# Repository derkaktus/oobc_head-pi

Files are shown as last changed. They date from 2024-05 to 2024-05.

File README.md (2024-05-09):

# OutofBand Console Server Head for Raspberry Pi

Upgrade your Raspberry Pi to an eight port serial console server for OoB management.

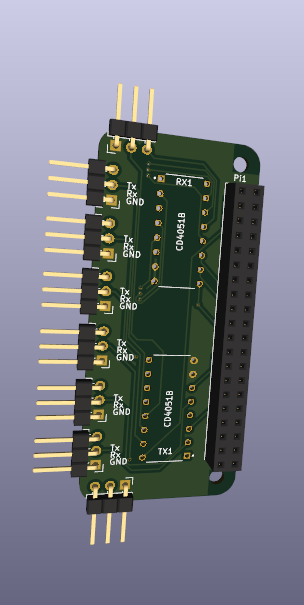
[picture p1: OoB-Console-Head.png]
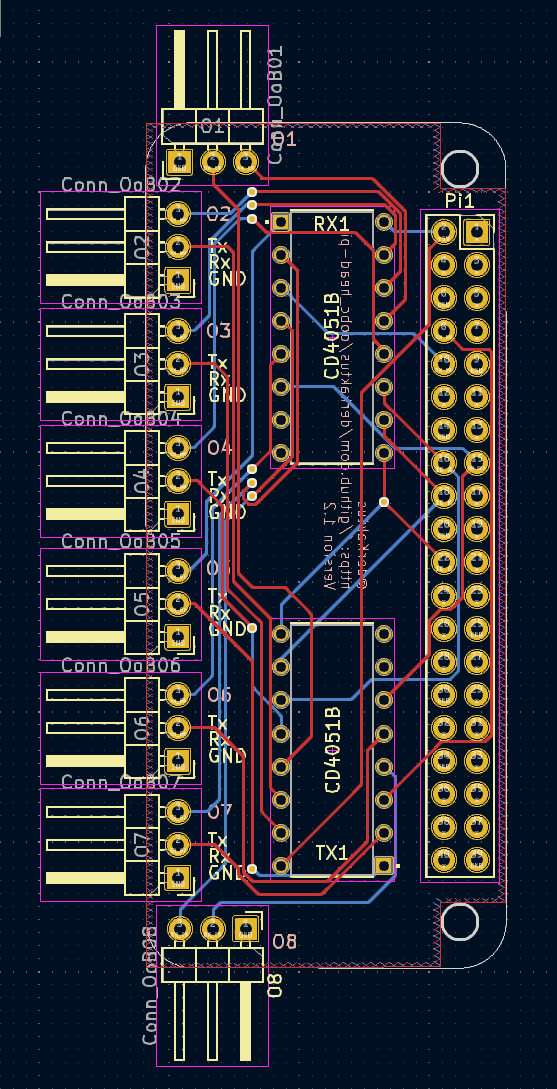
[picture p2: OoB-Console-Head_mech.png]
  
<br clear="left"/>
<br clear="right"/>

## Function
The head utilizes the build in UART capability of the raspberry pi (only UART0) and adds the 8 port switching capability. 
The port can be selected via pin 16, 18 and 22 a.k.a. **GPIO 22, 23** and **25** by adjusting their HIGH LOW state.

| PORT |GPIO>  | 22 | 23 | 25 |
|--|--| -- | -- | -- |
| 1 |  | 0 | 0 | 0 |
| 2 |  | 1 | 0 | 0 |
| 3 |  | 0 | 1 | 0 |
| 4 |  | 1 | 1 | 0 |
| 5 |  | 0 | 0 | 1 |
| 6 |  | 1 | 0 | 1 |
| 7 |  | 0 | 1 | 1 |
| 8 |  | 1 | 1 | 1 |

## Component
- 1x Pin Header 2x20 for Raspberry Pi
- 2x CD4051BE IC (Analog Multiplexer Single 8)

Optional: 
- 2x IC Socket 16 / 2x8 pin

Watch for the 2.54 mm pitch versions !!

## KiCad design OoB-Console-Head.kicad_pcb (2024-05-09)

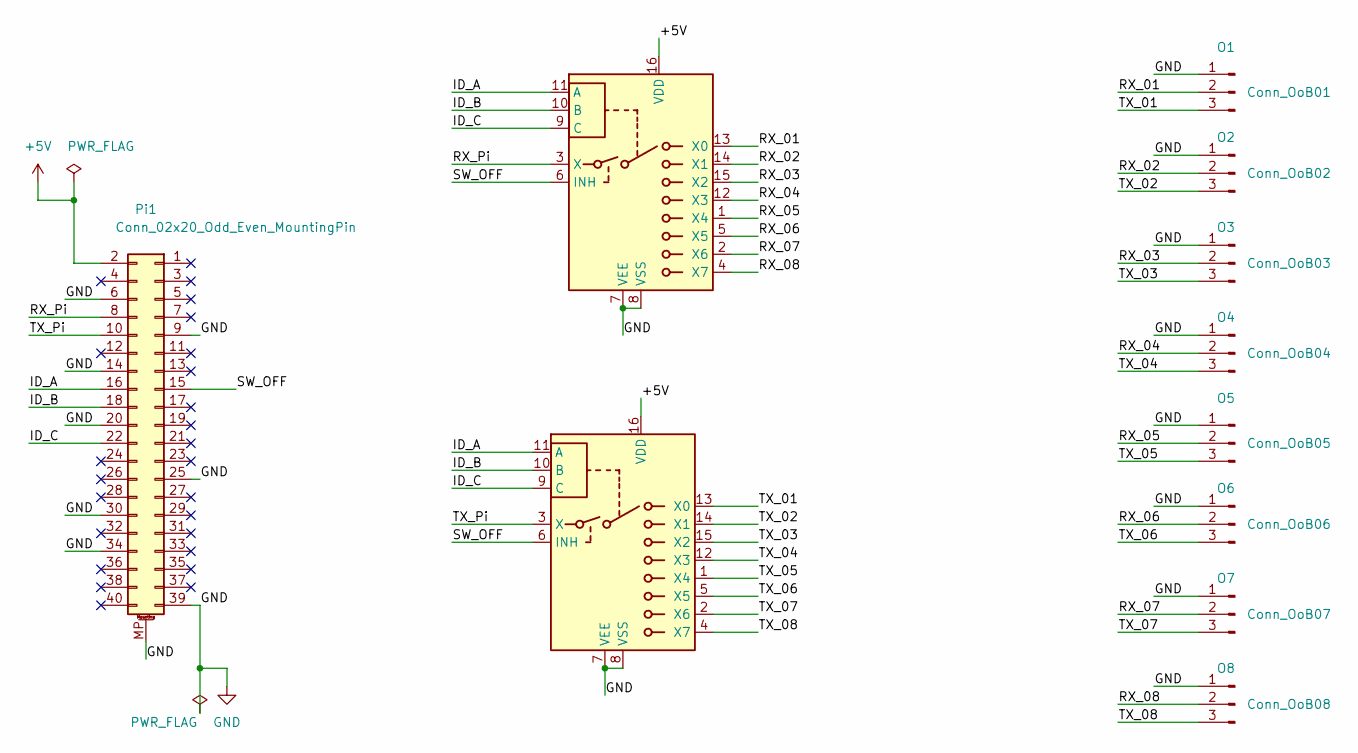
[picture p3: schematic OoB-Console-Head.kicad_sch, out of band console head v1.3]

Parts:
O1: Conn_OoB01; PinHeader_1x03_P2.54mm_Horizontal
O2: Conn_OoB02; PinHeader_1x03_P2.54mm_Horizontal
O3: Conn_OoB03; PinHeader_1x03_P2.54mm_Horizontal
O4: Conn_OoB04; PinHeader_1x03_P2.54mm_Horizontal
O5: Conn_OoB05; PinHeader_1x03_P2.54mm_Horizontal
O6: Conn_OoB06; PinHeader_1x03_P2.54mm_Horizontal
O7: Conn_OoB07; PinHeader_1x03_P2.54mm_Horizontal
O8: Conn_OoB08; PinHeader_1x03_P2.54mm_Horizontal
Pi1: Conn_02x20_Odd_Even_MountingPin; PinSocket_2x20_P2.54mm_Vertical
RX1: CD4051B; CD4051
TX1: CD4051B; CD4051

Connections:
+5V: Pi1.2, RX1.16 (VDD), TX1.16 (VDD)
/ID_A: Pi1.16, RX1.11 (A), TX1.11 (A)
/ID_B: Pi1.18, RX1.10 (B), TX1.10 (B)
/ID_C: Pi1.22, RX1.9 (C), TX1.9 (C)
/RX_01: O1.2, TX1.13 (X0)
/RX_02: O2.2, TX1.14 (X1)
/RX_03: O3.2, TX1.15 (X2)
/RX_04: O4.2, TX1.12 (X3)
/RX_05: O5.2, TX1.1 (X4)
/RX_06: O6.2, TX1.5 (X5)
/RX_07: O7.2, TX1.2 (X6)
/RX_08: O8.2, TX1.4 (X7)
/RX_Pi: Pi1.8, TX1.3 (X)
/SW_OFF: Pi1.15, RX1.6 (INH), TX1.6 (INH)
/TX_01: O1.3, RX1.13 (X0)
/TX_02: O2.3, RX1.14 (X1)
/TX_03: O3.3, RX1.15 (X2)
/TX_04: O4.3, RX1.12 (X3)
/TX_05: O5.3, RX1.1 (X4)
/TX_06: O6.3, RX1.5 (X5)
/TX_07: O7.3, RX1.2 (X6)
/TX_08: O8.3, RX1.4 (X7)
/TX_Pi: Pi1.10, RX1.3 (X)
GND: O1.1, O2.1, O3.1, O4.1, O5.1, O6.1, O7.1, O8.1, Pi1.6, Pi1.9, Pi1.14, Pi1.20, Pi1.25, Pi1.30, Pi1.34, Pi1.39, Pi1.MP (MountPin), RX1.7 (VEE), RX1.8 (VSS), TX1.7 (VEE), TX1.8 (VSS)

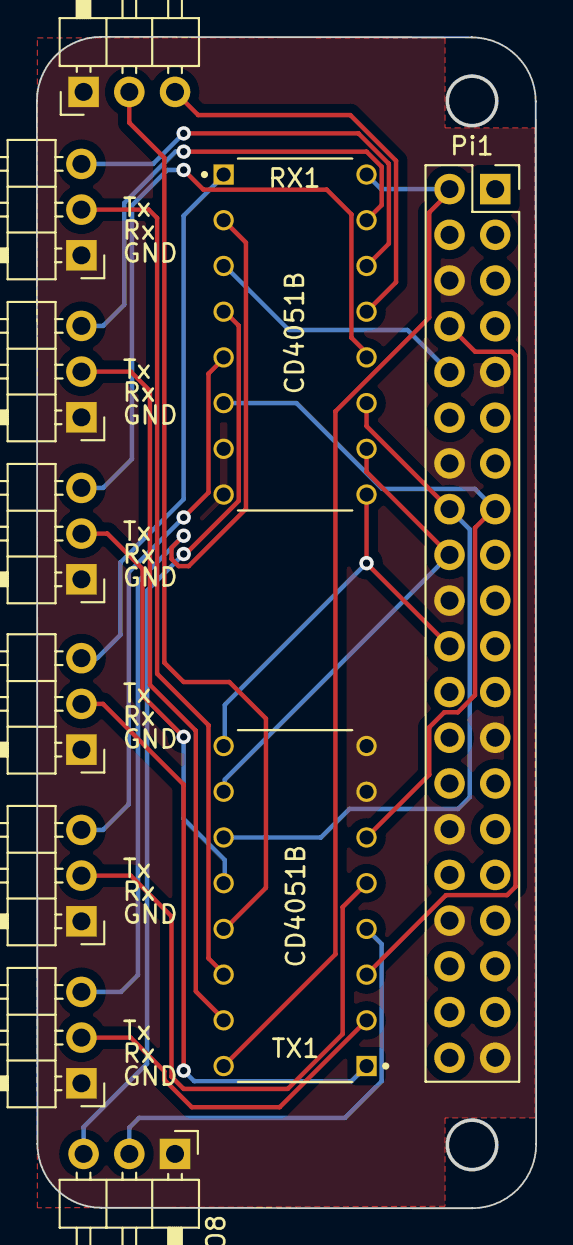
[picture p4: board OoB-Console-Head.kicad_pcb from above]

Board: 2 copper layers, 27.7 x 65.1 mm, 11 parts (0 on the bottom side), 24 nets.
